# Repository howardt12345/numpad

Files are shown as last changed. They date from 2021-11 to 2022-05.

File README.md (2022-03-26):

# [numpad](https://kb.ht12345.xyz/np0)
[][cc-by-nc-sa]

### Numpad with alt key, 2 rotary encoders, and OLED display. Designed to be used with a pro micro.

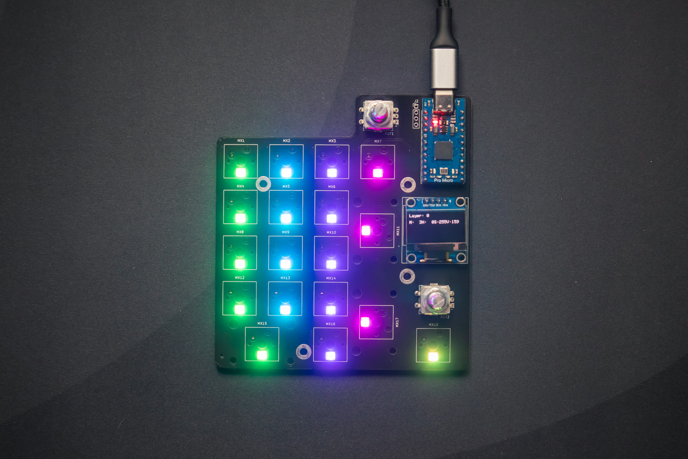
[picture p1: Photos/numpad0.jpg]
numpad0


## Specs:
- 2 Rotary Encoders
- 128x64 OLED display
- Per-key RGB matrix lighting
- Kailh Hotswap sockets
- QMK and Vial support

---
[The layout on keyboard layout editor](http://www.keyboard-layout-editor.com/#/gists/e6918e3b4176bcc28b69d0d3c7fc73e4)
[Photo gallery on @howardt12345](https://www.instagram.com/p/CbOJYpYOiaQ/)
[QMK (Pro Micro)](https://github.com/howardt12345/qmk_firmware/tree/ht12345/numpad/keyboards/ht12345/numpad)
[Vial (Pro Micro, KB2040)](https://github.com/howardt12345/vial-qmk/tree/ht12345/numpad/keyboards/ht12345/numpad)

---
## All of the files in this repository, including the PCBs, are provided without liability and without any guarantee with regards to functionality. Any production files and prototypes from this project are provided without warranty of any kind.

---

**This work is licensed under a** [Creative Commons Attribution-NonCommercial-ShareAlike 4.0 International License][cc-by-nc-sa].

[][cc-by-nc-sa]

[cc-by-nc-sa]: http://creativecommons.org/licenses/by-nc-sa/4.0/
[cc-by-nc-sa-image]: https://licensebuttons.net/l/by-nc-sa/4.0/88x31.png
[cc-by-nc-sa-shield]: https://img.shields.io/badge/License-CC%20BY--NC--SA%204.0-lightgrey.svg

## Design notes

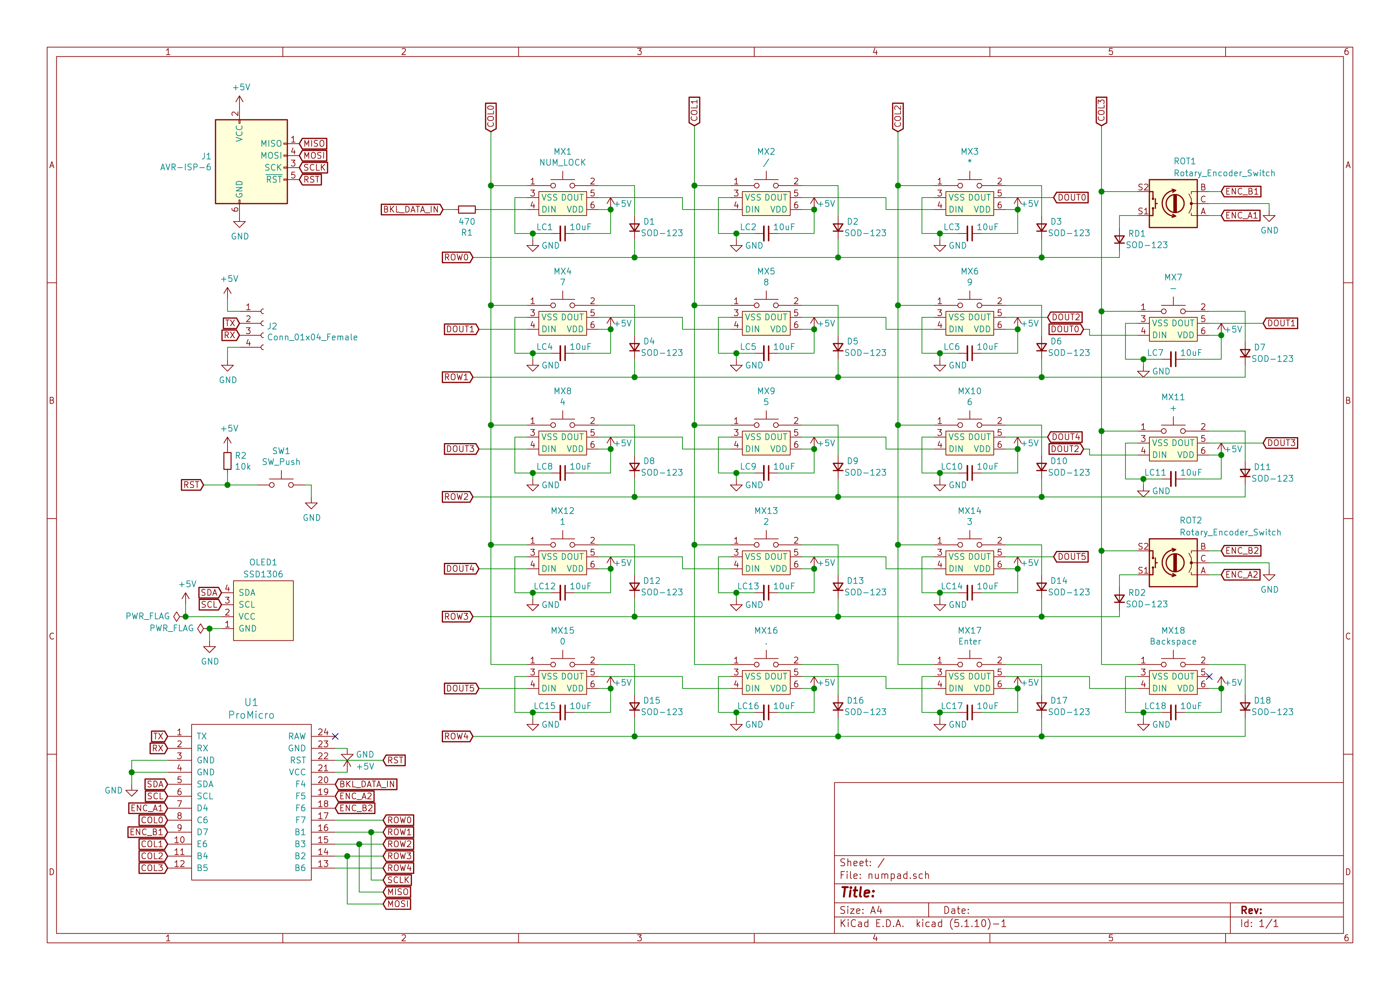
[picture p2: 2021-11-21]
PCB/Gerber/Pics/numpad.png

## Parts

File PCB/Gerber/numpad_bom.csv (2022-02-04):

Comment | Designator | Footprint | LCSC
100nF | C1,C10,C11,C12,C13,C14,C15,C16,C17,C18,C2,C3,C4,C5,C6,C7,C8,C9 | C_0603_1608Metric | C14663
470 | R1,R3 | R_0603_1608Metric | C23179
SW_Push | SW1 | SKQG-1155865 | C318884
SK6812MINI-E | LED1,LED10,LED11,LED12,LED13,LED14,LED15,LED16,LED17,LED18,LED2,LED3,LED4,LED5,LED6,LED7,LED8,LED9 | YS-SK6812MINI-E | C524051
D_Small | D1,D10,D11,D12,D13,D14,D15,D16,D17,D18,D2,D3,D4,D5,D6,D7,D8,D9,RD1,RD2 | D_SOD-123 | C81598

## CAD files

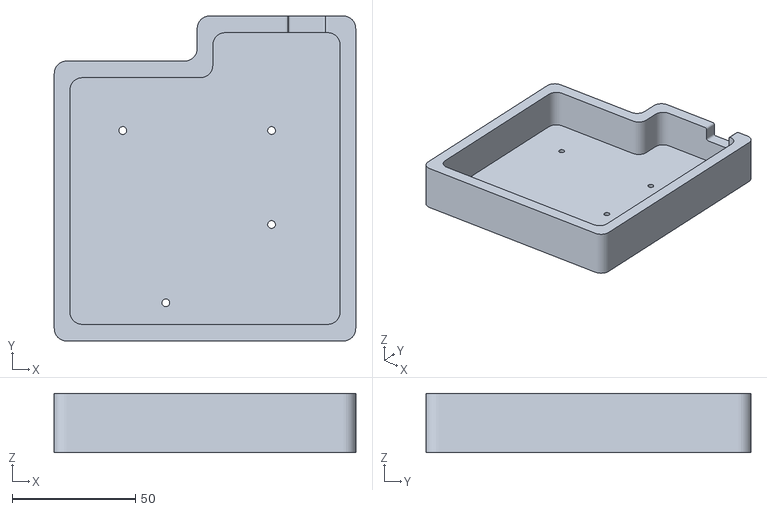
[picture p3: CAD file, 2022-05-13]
numpad case.stl
122.2 x 131.8 x 24.0

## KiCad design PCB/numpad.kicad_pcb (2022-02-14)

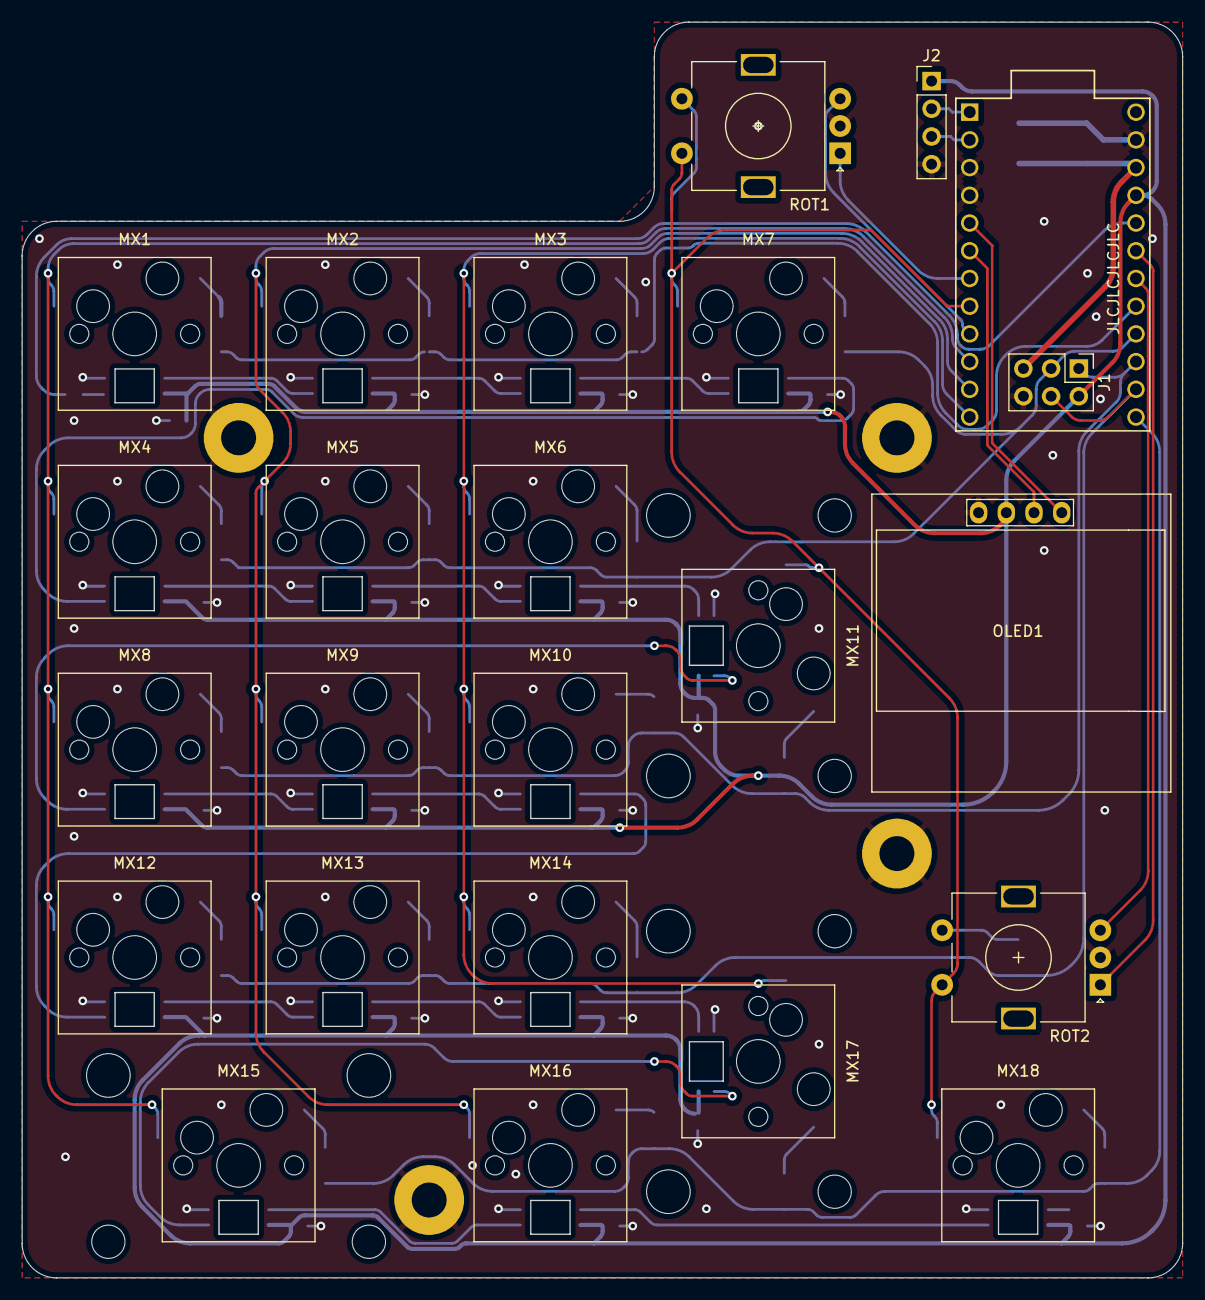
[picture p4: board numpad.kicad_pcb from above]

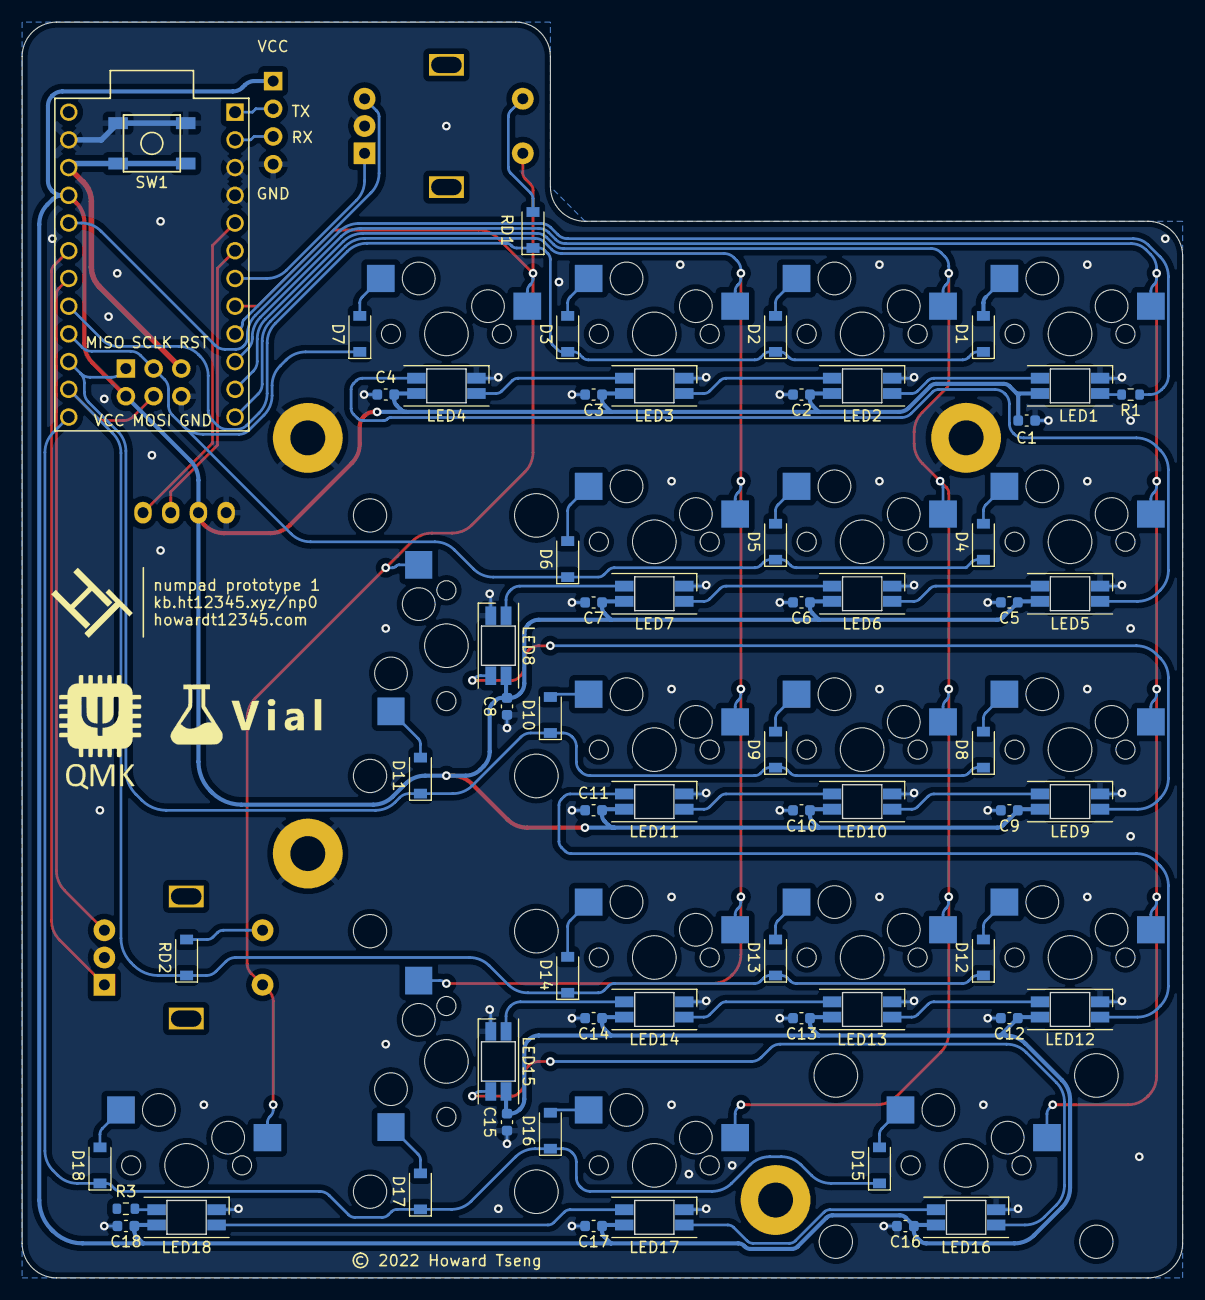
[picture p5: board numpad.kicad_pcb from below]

Board: 2 copper layers, 106.4 x 115.1 mm, 90 parts (61 on the bottom side), 60 nets.

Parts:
C1, C2, C3, C4, C5, C6, C7, C8, C9, C10, C11, C12, C13, C14, C15, C16, C17, C18: 100nF; C_0603_1608Metric
D1, D2, D3, D4, D5, D6, D7, D8, D9, D10, D11, D12, D13, D14, D15, D16, D17, D18: D_Small; D_SOD-123
H1, H2, H3, H4: M3; MountingHole_3.2mm_M3_Pad
J1: AVR-ISP-6; PinHeader_2x03_P2.54mm_Vertical
J2: Conn_01x04_Female; PinHeader_1x04_P2.54mm_Vertical
LED1, LED2, LED3, LED4, LED5, LED6, LED7, LED8, LED9, LED10, LED11, LED12, LED13, LED14, LED15, LED16, LED17, LED18: SK6812MINI-E; YS-SK6812MINI-E
LOGO1: Logo_Open_Hardware_Small; logo
LOGO2: Logo_Open_Hardware_Small; qmk_logo
LOGO3: Logo_Open_Hardware_Small; vial_logo
MX1, MX2, MX3, MX4, MX5, MX6, MX7, MX8, MX9, MX10, MX12, MX13, MX14, MX16: CherryMX; CherryMX_1.00u_PCB_KailhSocket
MX11, MX17: CherryMX; CherryMX_2.00u_PCB_KailhSocket_StabWireBottom
MX15: CherryMX; CherryMX_2.00u_PCB_KailhSocket_StabWireTop
MX18: CherryMX; CherryMX_1.50u_PCB_KailhSocket
OLED1: SSD1306; 128x64OLED
R1, R3: 470; R_0603_1608Metric
RD1, RD2: D_Small; D_SOD-123
ROT1, ROT2: Rotary_Encoder_Switch; RotaryEncoder_Alps_EC11E-Switch_Vertical_H20mm
SW1: SW_Push; SKQG-1155865
U1: ProMicro

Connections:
+5V: C1.1, C2.1, C3.1, C4.1, C5.1, C6.1, C7.1, C8.1, C9.1, C10.1, C11.1, C12.1, C13.1, C14.1, C15.1, C16.1, C17.1, C18.1, J1.2 (VCC), J2.1, LED1.1 (VDD), LED2.1 (VDD), LED3.1 (VDD), LED4.1 (VDD), LED5.1 (VDD), LED6.1 (VDD), LED7.1 (VDD), LED8.1 (VDD), LED9.1 (VDD), LED10.1 (VDD), LED11.1 (VDD), LED12.1 (VDD), LED13.1 (VDD), LED14.1 (VDD), LED15.1 (VDD), LED16.1 (VDD), LED17.1 (VDD), LED18.1 (VDD), OLED1.2 (VCC), U1.21 (VCC)
BKL_DATA_IN: R1.1, U1.20 (F4)
COL0: MX1.1, MX4.1, MX8.1, MX12.1, MX15.1, U1.10 (E6)
COL1: MX2.1, MX5.1, MX9.1, MX13.1, MX16.1, U1.11 (B4)
COL2: MX3.1, MX6.1, MX10.1, MX14.1, MX17.1, U1.12 (B5)
COL3: MX7.1, MX11.1, MX18.1, ROT1.S2, ROT2.S2, U1.8 (C6)
ENC_A1: ROT1.A, U1.7 (D4)
ENC_A2: ROT2.A, U1.19 (F5)
ENC_B1: ROT1.B, U1.9 (D7)
ENC_B2: ROT2.B, U1.18 (F6)
GND: C1.2, C2.2, C3.2, C4.2, C5.2, C6.2, C7.2, C8.2, C9.2, C10.2, C11.2, C12.2, C13.2, C14.2, C15.2, C16.2, C17.2, C18.2, H1.1, H2.1, H3.1, H4.1, J1.6 (GND), J2.4, LED1.3 (VSS), LED2.3 (VSS), LED3.3 (VSS), LED4.3 (VSS), LED5.3 (VSS), LED6.3 (VSS), LED7.3 (VSS), LED8.3 (VSS), LED9.3 (VSS), LED10.3 (VSS), LED11.3 (VSS), LED12.3 (VSS), LED13.3 (VSS), LED14.3 (VSS), LED15.3 (VSS), LED16.3 (VSS), LED17.3 (VSS), LED18.3 (VSS), OLED1.1 (GND), ROT1.C, ROT2.C, SW1.2, U1.3 (GND), U1.4 (GND), U1.23 (GND)
MISO: D8.1 (K), D9.1 (K), D10.1 (K), D11.1 (K), J1.1 (MISO), U1.15 (B3)
MOSI: D12.1 (K), D13.1 (K), D14.1 (K), J1.4 (MOSI), RD2.1 (K), U1.14 (B2)
unnamed: D1.2 (A), MX1.2
unnamed: D2.2 (A), MX2.2
unnamed: D3.2 (A), MX3.2
unnamed: D4.2 (A), MX4.2
unnamed: D5.2 (A), MX5.2
unnamed: D6.2 (A), MX6.2
unnamed: D7.2 (A), MX7.2
unnamed: D8.2 (A), MX8.2
unnamed: D9.2 (A), MX9.2
unnamed: D10.2 (A), MX10.2
unnamed: D11.2 (A), MX11.2
unnamed: D12.2 (A), MX12.2
unnamed: D13.2 (A), MX13.2
unnamed: D14.2 (A), MX14.2
unnamed: D15.2 (A), MX15.2
unnamed: D16.2 (A), MX16.2
unnamed: D17.2 (A), MX17.2
unnamed: D18.2 (A), MX18.2
unnamed: LED1.2 (DOUT), LED2.4 (DIN)
unnamed: LED1.4 (DIN), R1.2
unnamed: LED2.2 (DOUT), LED3.4 (DIN)
unnamed: LED3.2 (DOUT), LED4.4 (DIN)
unnamed: LED4.2 (DOUT), LED5.4 (DIN)
unnamed: LED5.2 (DOUT), LED6.4 (DIN)
unnamed: LED6.2 (DOUT), LED7.4 (DIN)
unnamed: LED7.2 (DOUT), LED8.4 (DIN)
unnamed: LED8.2 (DOUT), LED9.4 (DIN)
unnamed: LED10.2 (DOUT), LED11.4 (DIN)
unnamed: LED9.2 (DOUT), LED10.4 (DIN)
unnamed: LED11.2 (DOUT), LED12.4 (DIN)
unnamed: LED12.2 (DOUT), LED13.4 (DIN)
unnamed: LED13.2 (DOUT), LED14.4 (DIN)
unnamed: LED14.2 (DOUT), LED15.4 (DIN)
unnamed: LED15.2 (DOUT), LED16.4 (DIN)
unnamed: LED16.2 (DOUT), LED17.4 (DIN)
unnamed: LED17.2 (DOUT), LED18.4 (DIN)
unnamed: LED18.2 (DOUT), R3.1
unnamed: RD1.2 (A), ROT1.S1
unnamed: RD2.2 (A), ROT2.S1
ROW0: D1.1 (K), D2.1 (K), D3.1 (K), RD1.1 (K), U1.17 (F7)
ROW1: D4.1 (K), D5.1 (K), D6.1 (K), D7.1 (K), J1.3 (SCK), U1.16 (B1)
ROW4: D15.1 (K), D16.1 (K), D17.1 (K), D18.1 (K), U1.13 (B6)
RST: J1.5 (~RST), SW1.1, U1.22 (RST)
RX: J2.3, U1.2 (RX)
SCL: OLED1.3 (SCL), U1.6 (SCL)
SDA: OLED1.4 (SDA), U1.5 (SDA)
TX: J2.2, U1.1 (TX)

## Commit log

2021-11-20 Laid out the basic layout
    [numpad.kicad_pcb, numpad.sch]
2021-11-21 Switched to Pro Micro
    [numpad.kicad_pcb, numpad.sch]
2021-11-21 Refined traces and schematic for review
    [numpad.kicad_pcb, numpad.sch]
2021-11-21 Moved a via
    [numpad.kicad_pcb]
2021-11-21 Schematic pic export
2021-11-21 Exported gerber
    [numpad-B_Cu.gbr, numpad-B_Mask.gbr, numpad-B_Paste.gbr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]
2021-11-22 Added mounting holes
    [numpad - plate.kicad_pcb, numpad.kicad_pcb, numpad.sch]
2021-11-22 Adjusted plate outline
    [numpad - plate.kicad_pcb]
2021-11-22 Moved microcontroller by 1/4U
    [numpad.kicad_pcb]
2021-11-22 Exported gerbers
    [numpad - plate-B_Cu.gbr, numpad - plate-B_Mask.gbr, numpad - plate-B_Paste.gbr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]
2021-11-22 Exported proper gerber files for plate
    [numpad - plate-B_Cu.gbl, numpad - plate-B_Mask.gbs, numpad - plate-B_Paste.gbp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]
2021-11-22 Updated gerber export settings
    [numpad - plate.kicad_pcb, numpad.kicad_pcb]
2021-12-25 Cleaned up traces
    [numpad.kicad_pcb]
2022-01-14 Polished routing
    [numpad.kicad_pcb]
2022-01-16 Added logos, cleaned up routing
    [numpad-B_Cu.gbl, numpad-B_Mask.gbs, numpad-B_Paste.gbp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]
2022-01-16 Moved order number and exported production gerbers
    [numpad-B_Cu.gbl, numpad-B_Mask.gbs, numpad-B_Paste.gbp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]
2022-01-16 Removed ground fill from plate
    [numpad - plate-B_Cu.gbl, numpad - plate-B_Mask.gbs, numpad - plate-B_Paste.gbp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]
2022-01-16 numpad case 3d model
    [numpad case.stl]
2022-02-02 Updated to kicad 6
    [numpad.kicad_pcb, numpad.kicad_sch]
2022-02-03 Completely redid schematic and PCB
    [numpad.kicad_pcb, numpad.kicad_sch, rgb-leds.kicad_sch]
2022-02-03 Cleanup and exported gerbers
    [numpad-B_Cu.gbl, numpad-B_Mask.gbs, numpad-B_Paste.gbp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]
2022-02-03 Set up JLCPCB plugin
    [BOM-numpad.csv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]
2022-02-03 Added 3d models, cleaned up traces, exported gerbers
    [numpad-B_Cu.gbl, numpad-B_Mask.gbs, numpad-B_Paste.gbp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]
2022-02-03 zipped gerbers
    [numpad.kicad_pcb]
2022-02-04 Curved more traces
    [numpad.kicad_pcb, numpad.kicad_sch]
2022-02-04 Adjusted traces
    [numpad.kicad_pcb]
2022-02-14 Experimented with EVQWGD001 footprint
2022-02-14 changed plate url text
    [numpad - plate-B_Cu.gbl, numpad - plate-B_Mask.gbs, numpad - plate-B_Paste.gbp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]
2022-02-14 exported for production
    [POS-numpad.csv, numpad-B_Cu.gbl, numpad-B_Mask.gbs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]
2022-03-26 updated case file
    [numpad case.stl]
2022-03-26 Updated numpad switch labels
    [numpad.kicad_sch]
2022-05-13 Extended bottom by 1mm
    [numpad case.stl]

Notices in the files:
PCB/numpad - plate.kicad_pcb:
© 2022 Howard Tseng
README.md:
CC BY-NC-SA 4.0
